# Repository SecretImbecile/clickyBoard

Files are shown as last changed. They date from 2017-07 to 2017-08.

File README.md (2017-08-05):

# clickyBoard
A Raspberry Pi add-on board that adds a simple switch and LED circuit for GPIO programming, using mechanical keyboard switches

Read the [documentation file](Documentation/clickyBoard.pdf).

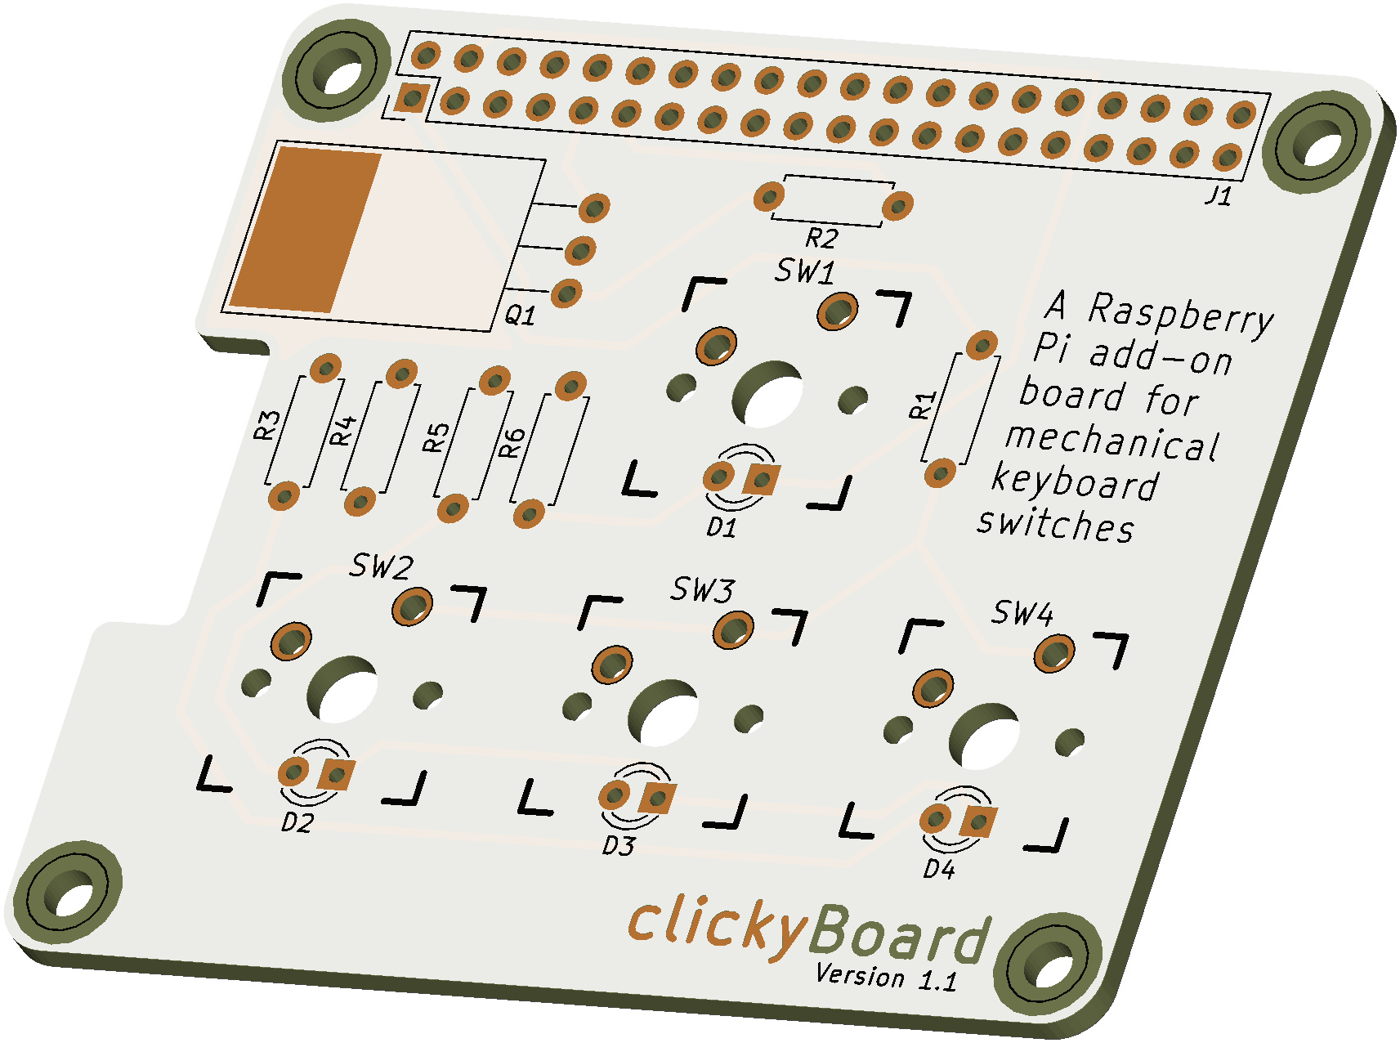
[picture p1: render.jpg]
clickyBoard PCB render


## Keyboard.pretty

Kicad files uses [Keyboard.pretty](https://github.com/stormbard/Keyboard.pretty), the KiCad Module Repository for keyboard PCB creation.

## FAQ

### What does clickyBoard add to my Pi?

clickyBoard adds a simple circuit to your Raspberry Pi for GPIO programming, featuring four input switches, as well as LED backlighting which can be controlled with a single output.

The board uses Cherry MX compatible switches, which are popular keyboard switches, that are widely and cheaply available along with compatible keycaps.

### Has the design been tested?

clickyBoard version 1.0 was manufactured and tested, and the discovered errors were rectified in board version 1.1. This latest version has not been manufactured as of yet, so please perform your own checks before sending the design off to be manufactured.

### Is this a HAT?

Not quite. The Raspberry Pi HAT [specification](https://github.com/raspberrypi/hats) requires a HAT to have an ID EEPROM. To keep this add-on board simple to assemble, this has been ommited. The clickyboard does adhere to the HAT mechanical specifications.

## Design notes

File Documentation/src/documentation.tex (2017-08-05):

\documentclass[10pt, a4paper, onesided]{article}

\usepackage{dingbat}
\usepackage{graphicx}
\usepackage{enumitem}
\renewcommand{\familydefault}{\sfdefault}
\usepackage[colorlinks=false]{hyperref}

\usepackage{listings}
\lstset{basicstyle=\small\ttfamily,breaklines=true}

\setlength{\parskip}{6pt}
\setlength{\parindent}{0pt}

%opening
\title{\textbf{clickyBoard} Documentation}
\author{}
\date{}

\begin{document}
\maketitle
\vspace{-60pt}

\begin{center}
	\textit{For board version 1.1}
\end{center}
\vspace{-12pt}
Download this document at \href{https://github.com/SecretImbecile/clickyBoard}{github.com/SecretImbecile/clickyBoard}
\tableofcontents

\section{The clickyBoard}

	The \textit{clickyBoard} is an add-on board for the Raspberry Pi computer (model B+ or later), which adds a simple switch and LED circuit for use in GPIO programming.
	
	The clickyBoard has been designed to use Cherry MX series switches or compatible switches from other manufacturers, designed for use in keyboards that are widely available and cheaply purchased.
	
	The board, through the Raspberry PI GPIO, provides four push-buttons inputs, as well as a single output through which you can control the four backlight LEDs under each key.
	
	In addition to technical documentation, this document also includes a parts list and assembly guide, for users wishing to assemble their own clickyBoard from scratch, or kit form.

\newpage
\section{Parts Required}

	The following components are required to fully populate a clickyBoard:
	
	\begin{itemize}[noitemsep]
		\item two $1 k\Omega$ resistors
		\item four T1 (3mm) LEDs
		\item four resistors, of a value determined in \autoref{LEDresistors}
		\item one TO-220 package logic level power MOSFET
		\item four Cherry MX compatible switches
		\item a female 40-pin connector for the Raspberry Pi GPIO header\footnote{a $2\times20$ header with $2.54 mm$ ($0.1"$) pitch}
	\end{itemize}
	
	\subsection{Mechanical Keyboard Switches}
	
	The clickyBoard has mounting holes for MX series or compatible switches. These are switches designed for use in premium computer keyboards, which are widely available, along with compatible keycaps.
	
	\begin{figure}[h]
		\centering
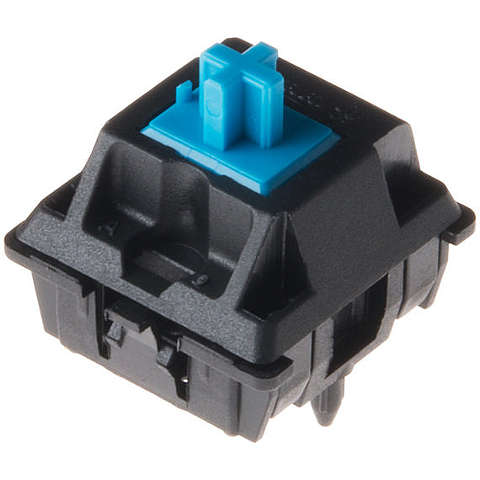
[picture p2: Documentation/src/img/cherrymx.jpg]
		
		\caption{A Cherry MX Blue switch}
		\label{fig:cherrymx}
	\end{figure}
	
	If you require quick delivery, the german manufactured \textbf{Cherry MX} series of switches are more readily available from several on-line retailers. In the United Kingdom, one possibility would be a computer hardware retailer like \href{http://www.kustompcs.co.uk/acatalog/Keys_and_Accessories.html}{kustompcs.co.uk}. In the US and internationally, \href{http://www.wasdkeyboards.com/index.php/products/keyboard-parts.html}{wasdkeyboards.com} specialises in mechanical keyboard parts. Cherry switches are likely to cost around \pounds1 per switch.
	
	If you're willing to wait for shipping from China, there are several manufacturers that make compatible switches, notably \textbf{Gateron} and \textit{Kailh} switches. Gateron switches can be purchased on eBay for as little as 10 for \pounds1.
	
	There are several types of MX switch available, denoted by the colour of their centre plunger, as shown in \autoref*{fig:cherrymx}. We recommend \textbf{blue} coloured switches, for full authentic clickiness, but others are available.
	
	If possible, opt for `\textbf{PCB mount}' switches (sometimes referred to as `5-pin'), as these have additional plastic pegs which will ensure the switches are correctly oriented. Using `plate mount' switches will usually result in slightly misaligned switches.
	
	\begin{center}
	\begin{tabular}{c|c|c|c}
		Switch Colour & Click & Tactile Bump & Heavy Spring \\ 
		\hline 
		Blue & \checkmark & \checkmark & \\ 
		Green & \checkmark & \checkmark & \checkmark \\ 
		Brown &  & \checkmark & \\ 
		Clear &  & \checkmark & \checkmark \\ 
		Red &  &  & \\ 
		Black &  &  & \checkmark \\ 
	\end{tabular}
	\end{center}

	\subsection{LED and Resistor Choice}
	\label{LEDresistors}

	To fit within the housing of an MX compatible switch, a 3mm (T1) LED must be chosen.
	
	To provide sufficient current, the LEDs on the clickyBoard are powered through the Raspberry Pi's 5 volt supply, rather than the current-limited 3V3 GPIO pins, and are instead controlled using a power MOSFET and a single GPIO output.
	
	Each LED has a resistor in series. The required resistance for the circuit can be calculated using this variant of the standard resistance formula, where $V_s$ is the supply voltage, and $V_f$ is the forward voltage of the chosen LED.
	
	\begin{displaymath}
		R = \frac{V_s - V_f}{I}
	\end{displaymath}
	
	For the red $2 V$ $20 mA$ LEDs used in the schematic, the resistance for the LED resistors was calculated as follows.
	
	\begin{displaymath}
		R = \frac{5 V - 2 V}{20 \times 10^{-3} A} = 150 \Omega
	\end{displaymath}

\newpage
\section{Assembly Guide}

	\subsection*{Soldering Basics}
		This guide will assume that the reader is familiar with basic soldering techniques. The components on the clickyBoard are all through-hole components, so it may be a suitable board for a novice solderer. Be aware that the 40-pin GPIO header can be tricky, especially with an old soldering iron, or thick gauge solder wire.
		
		With that said, here are some resources for learning to solder. Video tutorials are well suited for soldering, as you'll need to be able to identify a good solder joint from a bad one.
		\begin{itemize}[nolistsep]
			\item \textit{Soldering basics and choosing a cheap soldering iron} (00:00--12:00), bigclivedotcom --- \url{https://www.youtube.com/watch?v=aIab66EgfHM}
			\item \textit{EEVblog \#183 - Soldering Tutorial Part 2}, EEVblog --- \url{https://www.youtube.com/watch?v=fYz5nIHH0iY}
		\end{itemize}
	
	\subsection*{Resistors}
	
		For convenience, we always solder components from lowest height to highest, to maintain a steady PCB on which to work. Begin by soldering the two $1 k\Omega$ resistors in slots \texttt{r1} and \texttt{r2}.
		
		Next, solder the resistors for the LEDs that you chose in \autoref{LEDresistors} into the sockets \texttt{r3}--\texttt{r6}.
	
	\subsection*{MOSFET}
	
		Bend the legs of your TO-220 package MOSFET to a 90 degree angle and place it in the socket so that the large metal tab is flush with the PCB. You can optionally solder the tab to the large pad on the board, then solder the three main pins into their holes.
		
		If you are \textbf{not} using a MOSFET to control the LEDs, you should jumper the two topmost pins, either by bridging the holes with solder, or with a piece of wire.
	
	\subsection*{Switches \& LEDs}
	
		\subsubsection*{Switch assembly}
	
			In MX style switches, the 3mm LED sits in a slot at the bottom of the switch, and the leads are fed through holes in the switch housing. It is recommended to place the LED in the switch, then inserting that complete assembly into the board to solder.
			
			Ensure that the polarity of the LED is correct, and the switch is sitting flush with the board with the plastic peg(s) in their respective holes, then solder the connections of both the switch and LED.
	
	\subsection*{40-pin GPIO header}
	
		To complete the \textit{clickyBoard}, solder the 40-pin female header to the board, with the female socket on the reverse side of the board.
		
		If you choose not to solder all of the pins, the following pins are required (GPIO board pinout numbering): 
		\texttt{1 4 9 11 12 13 15 16}, omitting \texttt{11} if a MOSFET was not used.

\newpage
\section{Example Code}

The clickyBoard provides the following GPIO devices (all pins are GPIO board numbers):

\begin{itemize}[nosep]
	\item LED brightness control through pin \textbf{11}
	\item switch inputs through pins \textbf{12}, \textbf{13}, \textbf{15}, and \textbf{16}
\end{itemize}

The switch inputs require the internal GPIO pull-down resistors in the Raspberry Pi to be enabled. enable them by setting up the pins with the \texttt{pull\_up\_down} parameter set to \texttt{GPIO.PUD\_DOWN}.

The following example Python program will demonstrate the functionality of the clickyBoard. (note that \texttt{GPIO.cleanup()} is not run following this program)

\begin{lstlisting}[language=Python,title=clickyboardtest.py,numbers=left]
import RPi.GPIO as GPIO
import time

# Setup Pins
GPIO.setmode(GPIO.BOARD)

GPIO.setup(11, GPIO.OUT)
GPIO.setup(12, GPIO.IN, pull_up_down=GPIO.PUD_DOWN)
GPIO.setup(13, GPIO.IN, pull_up_down=GPIO.PUD_DOWN)
GPIO.setup(15, GPIO.IN, pull_up_down=GPIO.PUD_DOWN)
GPIO.setup(16, GPIO.IN, pull_up_down=GPIO.PUD_DOWN)

# Setup Backlight
pwm = GPIO.PWM(11, 60)
pwm.start(100)

while True:
	#Create a count of the buttons being pressed
	buttons_pressed = 0
	
	if GPIO.input(12) == GPIO.HIGH:
		buttons_pressed += 1
	if GPIO.input(13) == GPIO.HIGH:
		buttons_pressed += 1
	if GPIO.input(15) == GPIO.HIGH:
		buttons_pressed += 1
	if GPIO.input(16) == GPIO.HIGH:
		buttons_pressed += 1
	
	#Reduce PWM brightness based on number of buttons
	pwm.ChangeDutyCycle(100 - (25 * buttons_pressed))
	
	time.sleep(0.1)
	
\end{lstlisting}

\newpage
\section{Technical Documentation}
	\subsection{Schematic design for the clickyBoard}
		\begin{center}
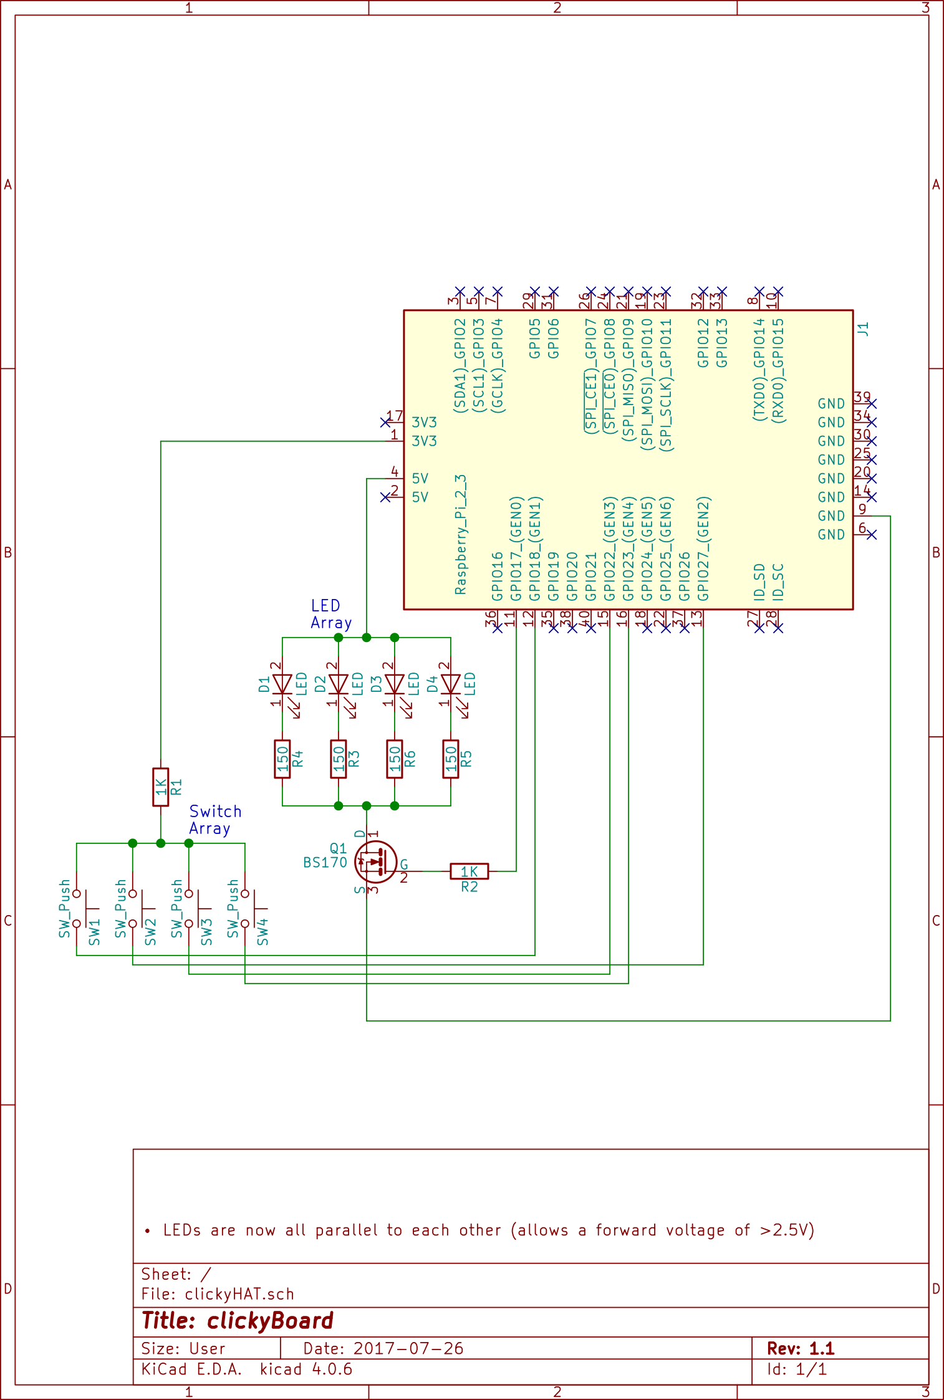
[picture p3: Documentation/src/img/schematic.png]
			
		\end{center}
	
	\newpage
	\subsection{PCB layout for the clickyBoard}
		Gerber outputs (with additional layers) are available on the \href{https://github.com/SecretImbecile/clickyBoard}{GitHub repo}.
		\subsubsection*{Front Copper}
			\begin{center}
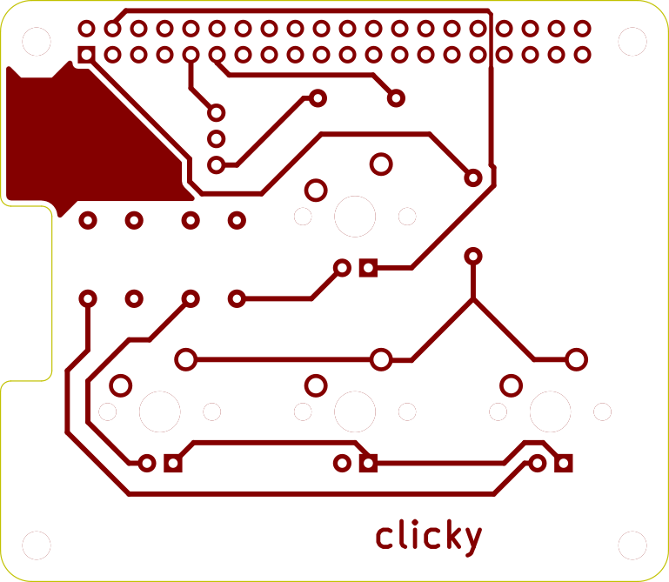
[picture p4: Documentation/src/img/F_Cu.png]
				
			\end{center}
		\subsubsection*{Back Copper}
		\begin{center}
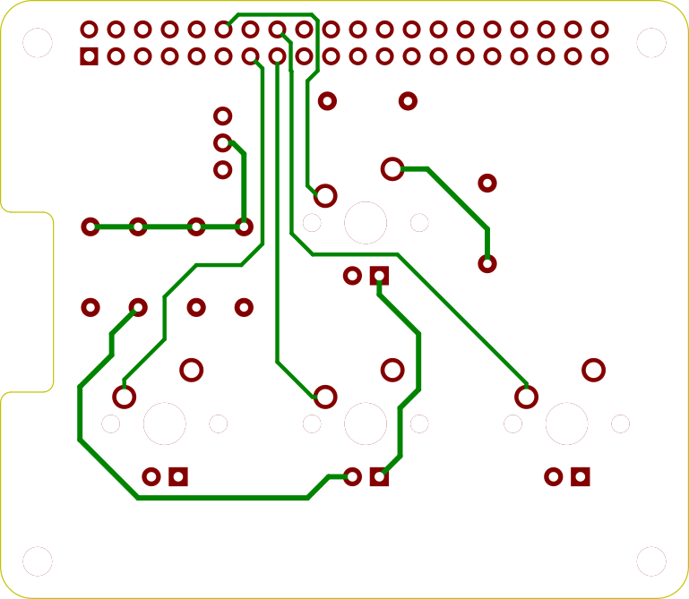
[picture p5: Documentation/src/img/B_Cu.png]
			
		\end{center}
		\subsubsection*{Front Silkscreen}
		\begin{center}
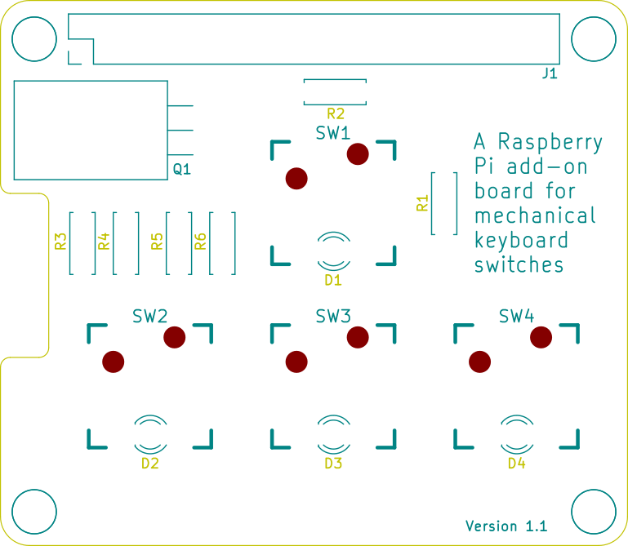
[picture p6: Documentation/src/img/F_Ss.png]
			
		\end{center}
	
	\subsection*{Design rules for PCB}

		The design rules used for this PCB were as follows.
	
		\begin{tabular}{c|c|c|c}
			Clearance & Track Width & Via Size & Silkscreen line thickness \\ 
			\hline 
			$0.2 mm$ & $\ge 0.375 mm$ & n/a & $\ge 0.15 mm$ \\ 
		\end{tabular}

\iffalse
	\subsection{Board errors in version 1.0}
	
		\subsubsection*{MOSFET miswiring}
		\label{MOSFETerror}
		
		Note that the mosfet pads are miswired on version 1.0, and the mosfet should be manually corrected with jumper wires. This has been rectified in version 1.1.
	
		\subsubsection*{LED pad direction}
		\label{LEDerror}
		
		Please note that the solder pads for the LEDs are reversed on board version 1.0. This has been rectified in version 1.1.
		
		By convention, the square solder pad indicates the positive side of a diode. However, because of an update to the \textit{KiCad} software, the pins in the component library were reversed. You should therefore solder the (longer) \textbf{positive} lead of the LEDs into the \textbf{circular} pads. 
		
		\begin{quote}
			\textit{...all diodes in KiCad's standard libraries have seen their pin numbers swapped. This is to be in line with most other software and the IPC standard as well, which states that cathode should be pin 1.}\footnote{\url{https://forum.kicad.info/t/important-announcement-diode-pins-swapped-in-standard-kicad-libraries/820}}
		\end{quote}
	
		\subsubsection*{LED array voltage}
		\label{LEDerror2}
		
		Due to the series arrangement of the LEDs in board version 1.0, blue LEDs would not be useable, this has been rectified in version 1.1.
		
		LEDs were arranged into 2 parallel series as shown in \autoref{fig:documentation}, providing each LED a maximum voltage of 2.5V. Because blue LEDs require a higher forward voltage, most blue and white LEDs will not work on version 1.0 of the clickyBoard, limiting you to red, yellow or green backlighting for most LEDs.
\fi

\newpage
\section{License}

	The complete hardware design for the clickyBoard, including the files made available on the clickyBoard \href{https://github.com/SecretImbecile/clickyBoard}{GitHub repo} and all documentation, are released in accordance with the \href{https://www.oshwa.org/definition/}{Open Source Hardware (OSHW) Definition}, under the \href{https://creativecommons.org/licenses/by-sa/4.0/}{\textbf{Creative Commons Attribution-ShareAlike 4.0 International (CC BY-SA 4.0)}} license.
	
	Every effort has been made to comply with the OSHW statement of principles. If you feel any aspect of the OSHW priciples have been neglected, please raise the issue with the creator (a GitHub issue report would be suitable).
\end{document}

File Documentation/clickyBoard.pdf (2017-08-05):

# clickyBoard Documentation

For board version 1.1
Download this document at github.com/SecretImbecile/clickyBoard

## Contents

1 The clickyBoard | 1
2 Parts Required | 2
3 Assembly Guide | 4
4 Example Code | 6
5 Technical Documentation | 7
6 License | 10

## 1 The clickyBoard

The clickyBoard is an add-on board for the Raspberry Pi computer (model B+ or later), which adds a simple switch and LED circuit for use in GPIO programming.

The clickyBoard has been designed to use Cherry MX series switches or compatible switches from other manufacturers, designed for use in keyboards that are widely available and cheaply purchased.

The board, through the Raspberry PI GPIO, provides four push-buttons inputs, as well as a single output through which you can control the four backlight LEDs under each key.

In addition to technical documentation, this document also includes a parts list and assembly guide, for users wishing to assemble their own clickyBoard from scratch, or kit form.

1

## 2 Parts Required

The following components are required to fully populate a clickyBoard:

- two 1kΩ resistors
- four T1 (3mm) LEDs
- four resistors, of a value determined in subsection 2.2
- one TO-220 package logic level power MOSFET
- four Cherry MX compatible switches
- a female 40-pin connector for the Raspberry Pi GPIO header¹

### 2.1 Mechanical Keyboard Switches

The clickyBoard has mounting holes for MX series or compatible switches. These are switches designed for use in premium computer keyboards, which are widely available, along with compatible keycaps.

Figure 1: A Cherry MX Blue switch

If you require quick delivery, the german manufactured Cherry MX series of switches are more readily available from several on-line retailers. In the United Kingdom, one possibility would be a computer hardware retailer like kustompcs.co.uk. (http://www.kustompcs.co.uk/acatalog/Keys_and_Accessories.html) In the US and internationally, wasdkeyboards.com (http://www.wasdkeyboards.com/index.php/products/keyboard-parts.html) specialises in mechanical keyboard parts. Cherry switches are likely to cost around £1 per switch.

If you’re willing to wait for shipping from China, there are several manufacturers that make compatible switches, notably Gateron and Kailh switches. Gateron switches can be purchased on eBay for as little as 10 for £1.

There are several types of MX switch available, denoted by the colour of their centre plunger, as shown in Figure 1. We recommend blue coloured switches, for full authentic clickiness, but others are available.

If possible, opt for ‘PCB mount’ switches (sometimes referred to as ‘5-pin’), as these have additional plastic pegs which will ensure the switches are correctly oriented. Using ‘plate mount’ switches will usually result in slightly misaligned switches.

1a 2 × 20 header with 2.54mm (0.1”) pitch

2

Switch Colour | Click | Tactile Bump | Heavy Spring
Blue | D | D
Green | D | D | D
Brown | | D
Clear | | D | D
Red
Black | | | D

### 2.2 LED and Resistor Choice

To fit within the housing of an MX compatible switch, a 3mm (T1) LED must be chosen.

To provide sufficient current, the LEDs on the clickyBoard are powered through the Raspberry Pi’s 5 volt supply, rather than the current-limited 3V3 GPIO pins, and are instead controlled using a power MOSFET and a single GPIO output.

Each LED has a resistor in series. The required resistance for the circuit can be calculated using this variant of the standard resistance formula, where Vs is the supply voltage, and Vf is the forward voltage of the chosen LED.

R =

Vs − Vf
I

For the red 2V 20mA LEDs used in the schematic, the resistance for the LED resistors was calculated as follows.

R =

5V − 2V
20 × 10⁻³A

= 150Ω

3

## 3 Assembly Guide

Soldering Basics

This guide will assume that the reader is familiar with basic soldering techniques. The components on the clickyBoard are all through-hole components, so it may be a suitable board for a novice solderer. Be aware that the 40-pin GPIO header can be tricky, especially with an old soldering iron, or thick gauge solder wire.

With that said, here are some resources for learning to solder. Video tutorials are well suited for soldering, as you’ll need to be able to identify a good solder joint from a bad one.

- Soldering basics and choosing a cheap soldering iron (00:00–12:00), bigclive-dotcom — https://www.youtube.com/watch?v=aIab66EgfHM
- EEVblog #183 - Soldering Tutorial Part 2, EEVblog — https://www.youtube.com/watch?v=fYz5nIHH0iY (https://www.youtube.com/watch?v=fYz5nIHH0iY)

Resistors

For convenience, we always solder components from lowest height to highest, to maintain a steady PCB on which to work. Begin by soldering the two 1kΩ resistors in slots r1 and r2.

Next, solder the resistors for the LEDs that you chose in subsection 2.2 into the sockets r3–r6.

MOSFET

Bend the legs of your TO-220 package MOSFET to a 90 degree angle and place it in the socket so that the large metal tab is flush with the PCB. You can optionally solder the tab to the large pad on the board, then solder the three main pins into their holes.

If you are not using a MOSFET to control the LEDs, you should jumper the two topmost pins, either by bridging the holes with solder, or with a piece of wire.

Switches & LEDs

Switch assembly

In MX style switches, the 3mm LED sits in a slot at the bottom of the switch, and the leads are fed through holes in the switch housing. It is recommended to place the LED in the switch, then inserting that complete assembly into the board to solder.

Ensure that the polarity of the LED is correct, and the switch is sitting flush with the board with the plastic peg(s) in their respective holes, then solder the connections of both the switch and LED.

4

40-pin GPIO header

To complete the clickyBoard, solder the 40-pin female header to the board, with the female socket on the reverse side of the board.

If you choose not to solder all of the pins, the following pins are required (GPIO board pinout numbering): 1 4 9 11 12 13 15 16, omitting 11 if a MOSFET was not used.

5

## 4 Example Code

The clickyBoard provides the following GPIO devices (all pins are GPIO board numbers):

- LED brightness control through pin 11
- switch inputs through pins 12, 13, 15, and 16

The switch inputs require the internal GPIO pull-down resistors in the Raspberry Pi to be enabled. enable them by setting up the pins with the pull up down parameter set to GPIO.PUD DOWN.

The following example Python program will demonstrate the functionality of the clickyBoard. (note that GPIO.cleanup() is not run following this program)

clickyboardtest.py

1 | import RPi . GPIO as GPIO
2 | import time
3
4 | # Setup Pins
5 | GPIO . setmode ( GPIO . BOARD )
6
7 | GPIO . setup (11 , GPIO . OUT )
8 | GPIO . setup (12 , GPIO . IN , pull_up_down = GPIO . PUD_DOWN )
9 | GPIO . setup (13 , GPIO . IN , pull_up_down = GPIO . PUD_DOWN )
10 | GPIO . setup (15 , GPIO . IN , pull_up_down = GPIO . PUD_DOWN )
11 | GPIO . setup (16 , GPIO . IN , pull_up_down = GPIO . PUD_DOWN )
12
13 | # Setup Backlight
14 | pwm = GPIO . PWM (11 , 60)
15 | pwm . start (100)
16
17 | while True :
18 | # Create a count of the buttons being pressed
19 | buttons_pressed = 0
20
21 | if GPIO . input (12) == GPIO . HIGH :
22 | buttons_pressed += 1
23 | if GPIO . input (13) == GPIO . HIGH :
24 | buttons_pressed += 1
25 | if GPIO . input (15) == GPIO . HIGH :
26 | buttons_pressed += 1
27 | if GPIO . input (16) == GPIO . HIGH :
28 | buttons_pressed += 1
29
30 | # Reduce PWM brightness based on number of buttons
31 | pwm . ChangeDutyCycle (100 - (25 * buttons_pressed ) )
32
33 | time . sleep (0.1)

6

## 5 Technical Documentation

### 5.1 Schematic design for the clickyBoard

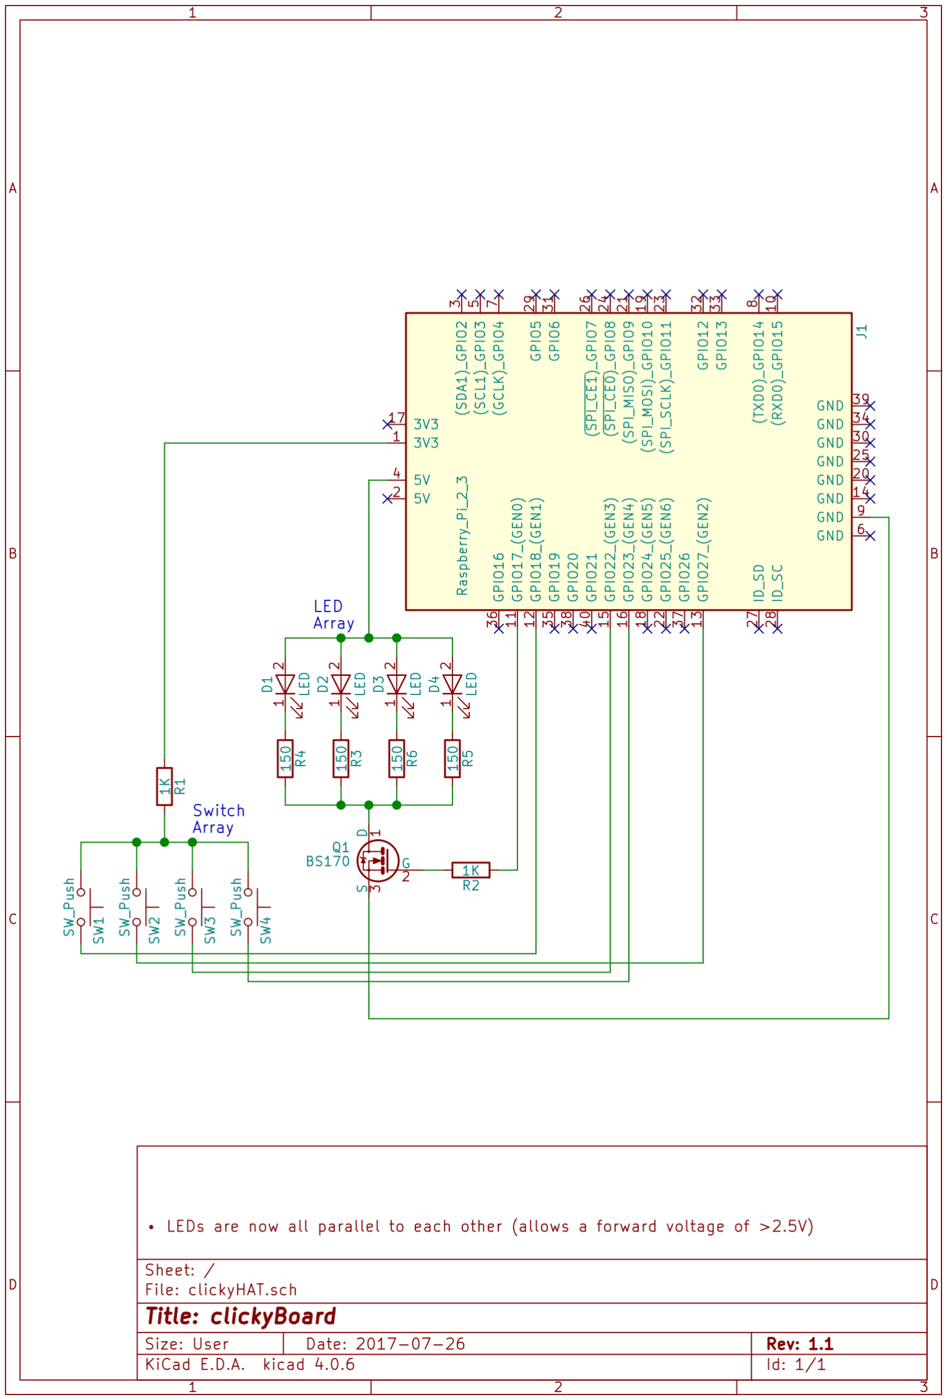
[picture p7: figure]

7

### 5.2 PCB layout for the clickyBoard

Gerber outputs (with additional layers) are available on the GitHub repo. (https://github.com/SecretImbecile/clickyBoard)

Front Copper

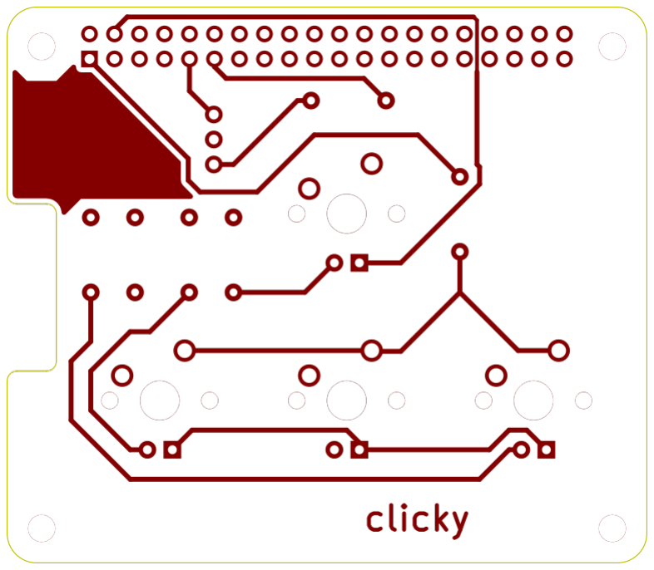
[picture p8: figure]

Back Copper

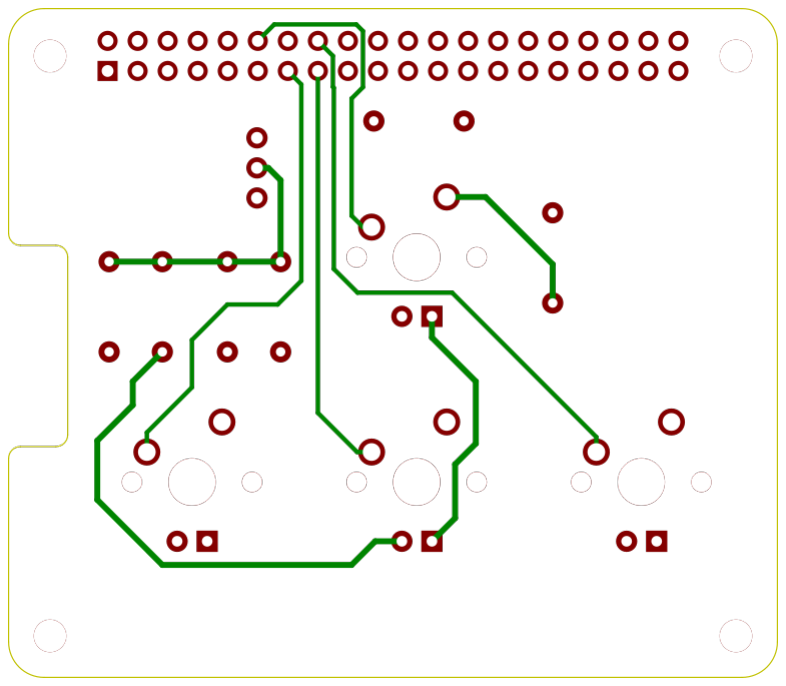
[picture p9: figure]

8

Front Silkscreen

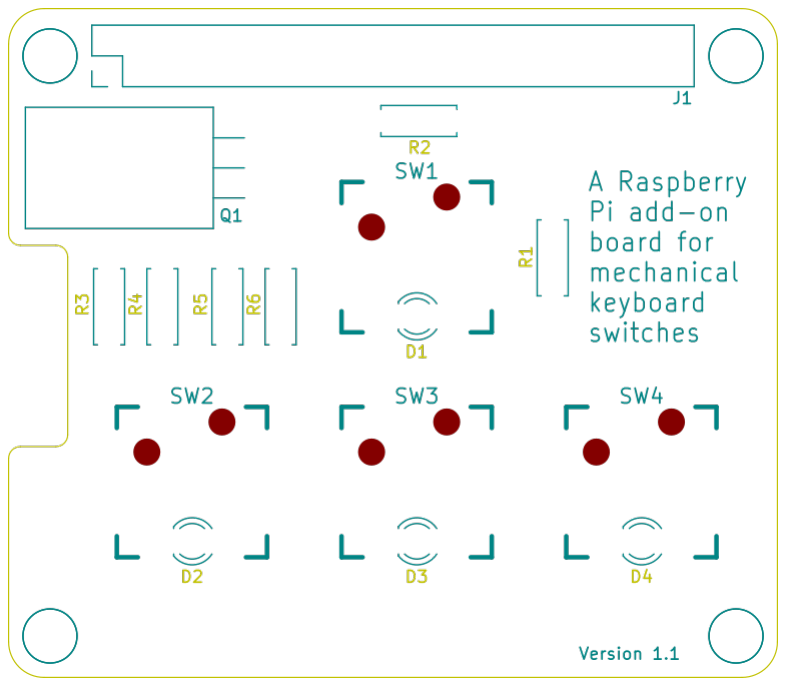
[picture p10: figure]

Design rules for PCB

The design rules used for this PCB were as follows.

Clearance | Track Width | Via Size | Silkscreen line thickness
0.2mm | ≥ 0.375mm | n/a | ≥ 0.15mm

9

## 6 License

The complete hardware design for the clickyBoard, including the files made available on the clickyBoard GitHub repo (https://github.com/SecretImbecile/clickyBoard) and all documentation, are released in accordance with the Open Source Hardware (OSHW) Definition, (https://www.oshwa.org/definition/) under the Creative Commons Attribution-ShareAlike 4.0 International (CC BY-SA 4.0) (https://creativecommons.org/licenses/by-sa/4.0/) license.

Every effort has been made to comply with the OSHW statement of principles. If you feel any aspect of the OSHW priciples have been neglected, please raise the issue with the creator (a GitHub issue report would be suitable).

10

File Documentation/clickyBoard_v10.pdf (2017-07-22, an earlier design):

# Documentation for the clickyBoard

Download this document at github.com/SecretImbecile/clickyBoard

## Contents

1 The clickyBoard | 1
2 Parts Required | 2
3 Assembly Guide | 4
4 Example Code | 6
5 Technical Documentation | 7
6 License | 9

## 1 The clickyBoard

The clickyBoard is an add-on board for the Raspberry Pi computer (model B+ or later), which adds a simple switch and LED circuit for use in GPIO programming.

The clickyBoard has been designed to use Cherry MX series switches or compatible switches from other manufacturers, designed for use in keyboards that are widely available and cheaply purchased.

The board, through the Raspberry PI GPIO, provides four push-buttons inputs, as well as a single output through which you can control the four backlight LEDs under each key.

In addition to technical documentation, this document also includes a parts list and assembly guide, for users wishing to assemble their own clickyBoard from scratch, or kit form.

1

## 2 Parts Required

The following components are required to fully populate a clickyBoard:

- two 1kΩ resistors
- four T1 (3mm) LEDs
- two/four resistors, of a value determined in subsection 2.2
- one TO-220 package logic level power MOSFET
- four Cherry MX compatible switches
- a female 40-pin connector for the Raspberry Pi GPIO header¹

### 2.1 Mechanical Keyboard Switches

The clickyBoard has mounting holes for MX series or compatible switches. These are switches designed for use in premium computer keyboards, which are widely available, along with compatible keycaps.

Figure 1: A Cherry MX Blue switch

If you require quick delivery, the german manufactured Cherry MX series of switches are more readily available from several on-line retailers. In the United Kingdom, one possibility would be a computer hardware retailer like kustompcs.co.uk. (http://www.kustompcs.co.uk/acatalog/Keys_and_Accessories.html) In the US and internationally, wasdkeyboards.com (http://www.wasdkeyboards.com/index.php/products/keyboard-parts.html) specialises in mechanical keyboard parts. Cherry switches are likely to cost around £1 per switch.

If you’re willing to wait for shipping from China, there are several manufacturers that make compatible switches, notably Gateron and Kailh switches. Gateron switches can be purchased on eBay for as little as 10 for £1.

There are several types of MX switch available, denoted by the colour of their centre plunger, as shown in Figure 1. We recommend blue coloured switches, for full authentic clickiness, but others are available. If possible, opt for ‘PCB mount’ switches (sometimes referred to as ‘5-pin’), as these have additional plastic pegs which will somewhat improve stability on the PCB.

1a 2 × 20 header with 2.54mm (0.1”) pitch

2

Switch Colour | Click | Tactile Bump | Heavy Spring
Blue | D | D
Green | D | D | D
Brown | | D
Clear | | D | D
Red
Black | | | D

### 2.2 LED and Resistor Choice

To fit within the housing of an MX compatible switch, a 3mm (T1) LED must be chosen.

To provide ample current, the LEDs on the clickyBoard are powered through the Raspberry Pi’s 5 volt supply, with the LEDs arranged in two parallel series, as shown in Figure 2.

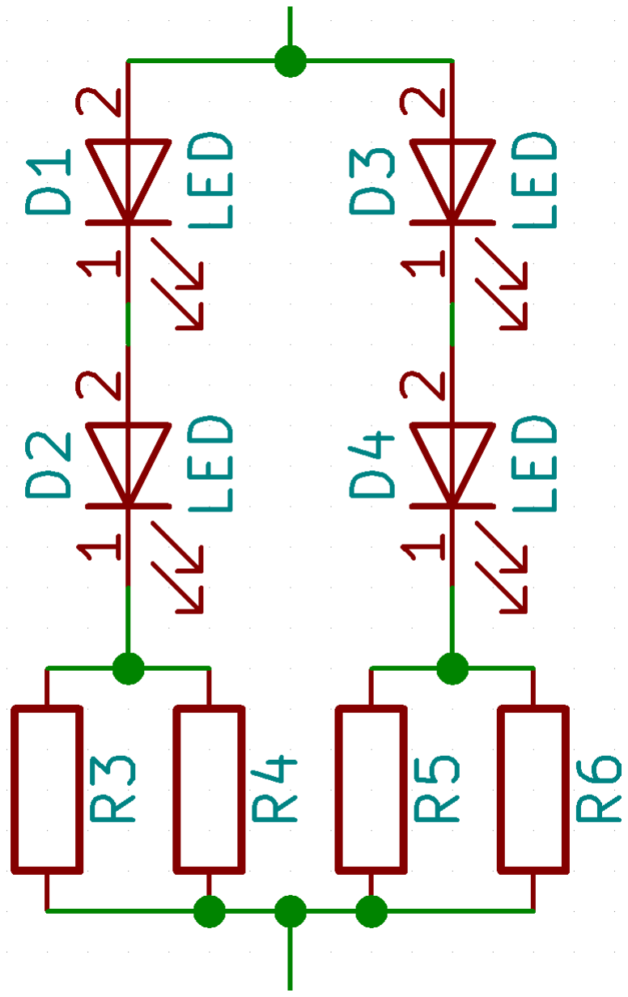
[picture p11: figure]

Figure 2: Wiring schematic for the four resistor sockets

The required resistance for the circuit can be calculated using the standard formula, where Vs is the supply voltage, and Vf is the forward voltage of the chosen LED.

R =

Vs − Vf
I

As each half has two LEDs in series, the forward voltage used is double the value of a single LED. For the 2V 20mA LEDs used in the schematic, the resistance was calculated as follows.

R =

5V − (2 × 2V )
20 × 10⁻³

= 50Ω

The circuit can therefore be completed with two 50Ω resistors. Two additional spaces are provided, so four 100Ω resistors could be used if they are more readily available.

3

## 3 Assembly Guide

Soldering Basics

This guide will assume that the reader is familiar with basic soldering techniques. The components on the clickyBoard are all through-hole components, so it may be a suitable board for a novice solderer. Be aware that the 40-pin GPIO header can be tricky, especially with an old soldering iron, or thick gauge solder wire.

With that said, here are some resources for learning to solder. Video tutorials are well suited for soldering, as you’ll need to be able to identify a good solder joint from a bad one.

- Soldering basics and choosing a cheap soldering iron (00:00–12:00), bigclive-dotcom — https://www.youtube.com/watch?v=aIab66EgfHM
- EEVblog #183 - Soldering Tutorial Part 2, EEVblog — https://www.youtube.com/watch?v=fYz5nIHH0iY (https://www.youtube.com/watch?v=fYz5nIHH0iY)

Resistors

For convenience, we always solder components from lowest height to highest, to maintain a steady PCB on which to work. Begin by soldering the two 1kΩ resistors in slots r1 and r2.

Next, solder the resistors for the LED array that you chose in subsection 2.2 into the sockets r3–r6. If you are using two resistors, ensure the circuit is completed1 in accordance to Figure 2.

MOSFET

Bend the legs of your TO-220 package MOSFET to a 90 degree angle and place it in the socket so that the large metal tab is flush with the PCB, then solder the three pins. You can optionally solder the tab to the plated mounting hole.

If you are not using a MOSFET to control the LEDs, you should jumper the two outermost pins with a piece of insulated wire or an ≈ 0Ω resistor. Ensure that the jumper wire does not short with the centre contact pad.

Switches & LEDs

Erratum: LED pad direction

Please note that the solder pads for the LEDs are reversed. By convention, the square solder pad indicates the positive side of a diode. However, because of an update to the KiCad software, the pins in the component library were reversed. You should therefore solder the (longer) positive lead of the LEDs into the circular pads.

4

...all diodes in KiCad’s standard libraries have seen their pin numbers swapped. This is to be in line with most other software and the IPC standard as well, which states that cathode should be pin 1.²

Switch assembly

In MX style switches, the 3mm LED sits in a slot at the bottom of the switch, and the leads are fed through holes in the switch housing. It is recommended to place the LED in the switch, then inserting that complete assembly into the board to solder.

Ensure that the polarity of the LED is correct, and the switch is sitting flush with the board with the plastic peg(s) in their respective holes, then solder the connections of both the switch and LED.

40-pin GPIO header

To complete the clickyBoard, solder the 40-pin female header to the board, with the female socket on the reverse side of the board.

If you choose not to solder all of the pins, the following pins are required (GPIO board pinout numbering): 1 4 9 11 12 13 15 16, omitting 11 if a MOSFET was not used.

2https://forum.kicad.info/t/important-announcement-diode-pins-swapped-in-standard-kicad-libraries/

820 (https://forum.kicad.info/t/important-announcement-diode-pins-swapped-in-standard-kicad-libraries/820)

5

## 4 Example Code

The clickyBoard provides the following GPIO devices (all pins are GPIO board numbers):

- LED brightness control through pin 11
- switch inputs through pins 12, 13, 15, and 16

The switch inputs require the internal GPIO pull-down resistors in the Raspberry Pi to be enabled. enable them by setting up the pins with the pull up down parameter set to GPIO.PUD DOWN.

The following example Python program will demonstrate the functionality of the clickyBoard. (note that GPIO.cleanup() is not run following this program)

clickyboardtest.py

1 | import RPi . GPIO as GPIO
2 | import time
3
4 | # Setup Pins
5 | GPIO . setmode ( GPIO . BOARD )
6
7 | GPIO . setup (11 , GPIO . OUT )
8 | GPIO . setup (12 , GPIO . IN , pull_up_down = GPIO . PUD_DOWN )
9 | GPIO . setup (13 , GPIO . IN , pull_up_down = GPIO . PUD_DOWN )
10 | GPIO . setup (15 , GPIO . IN , pull_up_down = GPIO . PUD_DOWN )
11 | GPIO . setup (16 , GPIO . IN , pull_up_down = GPIO . PUD_DOWN )
12
13 | # Setup Backlight
14 | pwm = GPIO . PWM (11 , 60)
15 | pwm . start (100)
16
17 | while True :
18 | # Create a count of the buttons being pressed
19 | buttons_pressed = 0
20
21 | if GPIO . input (12) == GPIO . HIGH :
22 | buttons_pressed += 1
23 | if GPIO . input (13) == GPIO . HIGH :
24 | buttons_pressed += 1
25 | if GPIO . input (15) == GPIO . HIGH :
26 | buttons_pressed += 1
27 | if GPIO . input (16) == GPIO . HIGH :
28 | buttons_pressed += 1
29
30 | # Reduce PWM brightness based on number of buttons
31 | pwm . ChangeDutyCycle (100 - (25 * buttons_pressed ) )
32
33 | time . sleep (0.1)

6

## 5 Technical Documentation

### 5.1 Schematic design for the clickyBoard

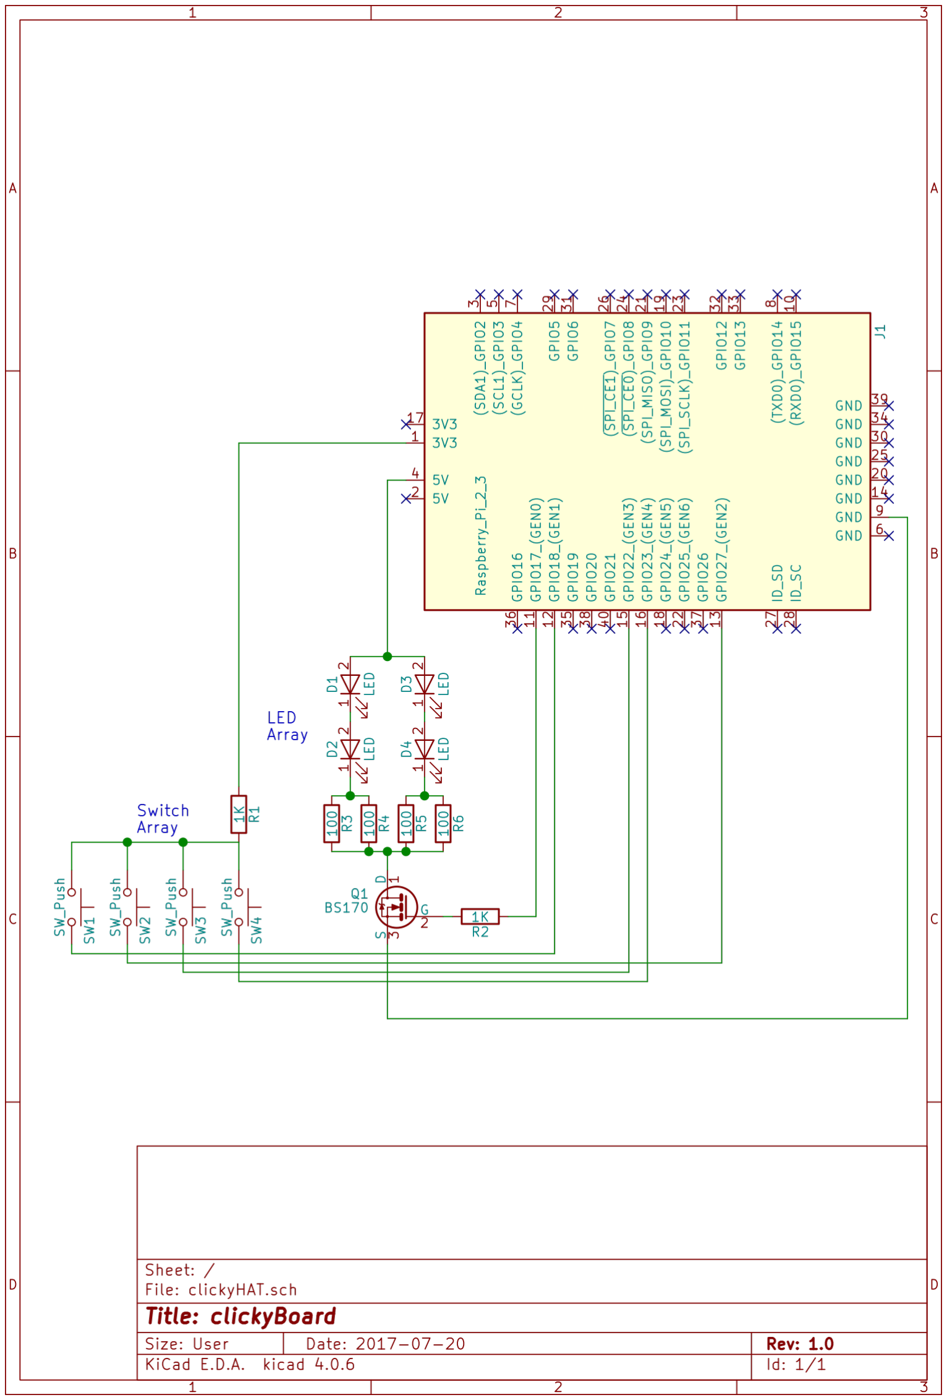
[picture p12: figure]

7

### 5.2 PCB layout for the clickyBoard

Gerber outputs (with additional layers) are available on the github repo. (https://github.com/SecretImbecile/clickyBoard)

Front Copper

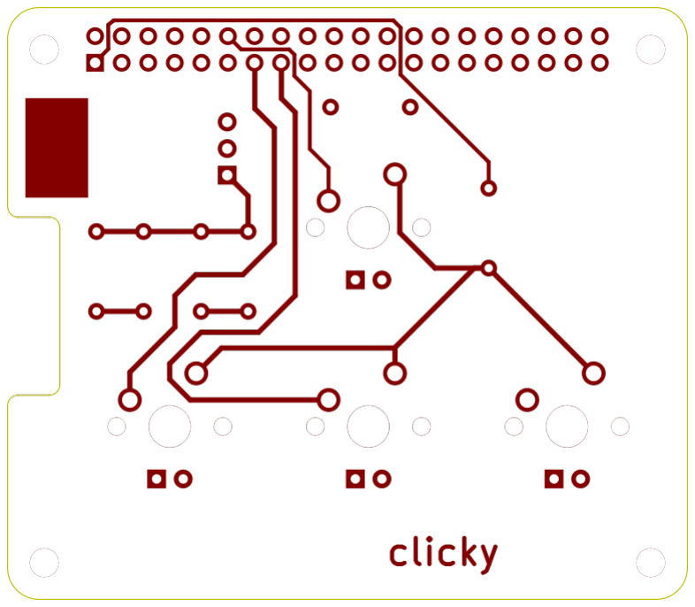
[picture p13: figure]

Back Copper

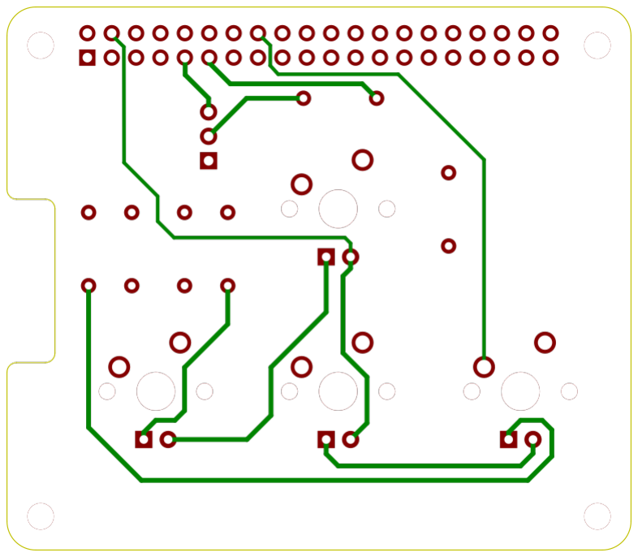
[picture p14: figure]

8

Front Silkscreen

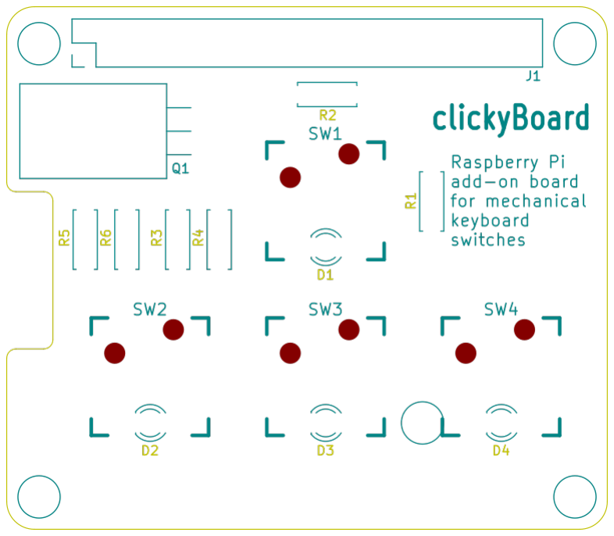
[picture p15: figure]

### 5.3 Design rules for PCB

The design rules used for this PCB were as follows.

Clearance | Track Width | Via Size | Silkscreen line thickness
0.2mm | ≥ 0.375mm | n/a | ≥ 0.15mm

## 6 License

The complete hardware design for the clickyBoard, including the files made available on the clickyBoard Github repo (https://github.com/SecretImbecile/clickyBoard) and all documentation, are released in accordance with the Open Source Hardware (OSHW) Definition, (https://www.oshwa.org/definition/) under the Creative Commons Attribution-ShareAlike 4.0 International (CC BY-SA 4.0) (https://creativecommons.org/licenses/by-sa/4.0/) license.

Every effort has been made to comply with the OSHW statement of principles. If you feel any aspect of the OSHW priciples have been neglected, please raise the issue with the creator (a github issue report would be suitable).

9

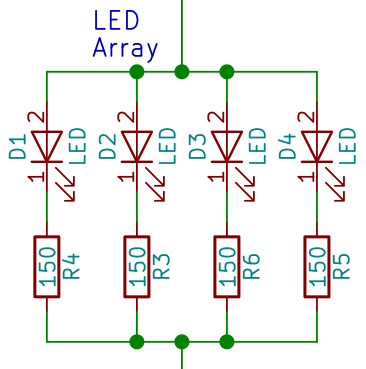
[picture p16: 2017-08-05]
Documentation/src/img/resistor.png

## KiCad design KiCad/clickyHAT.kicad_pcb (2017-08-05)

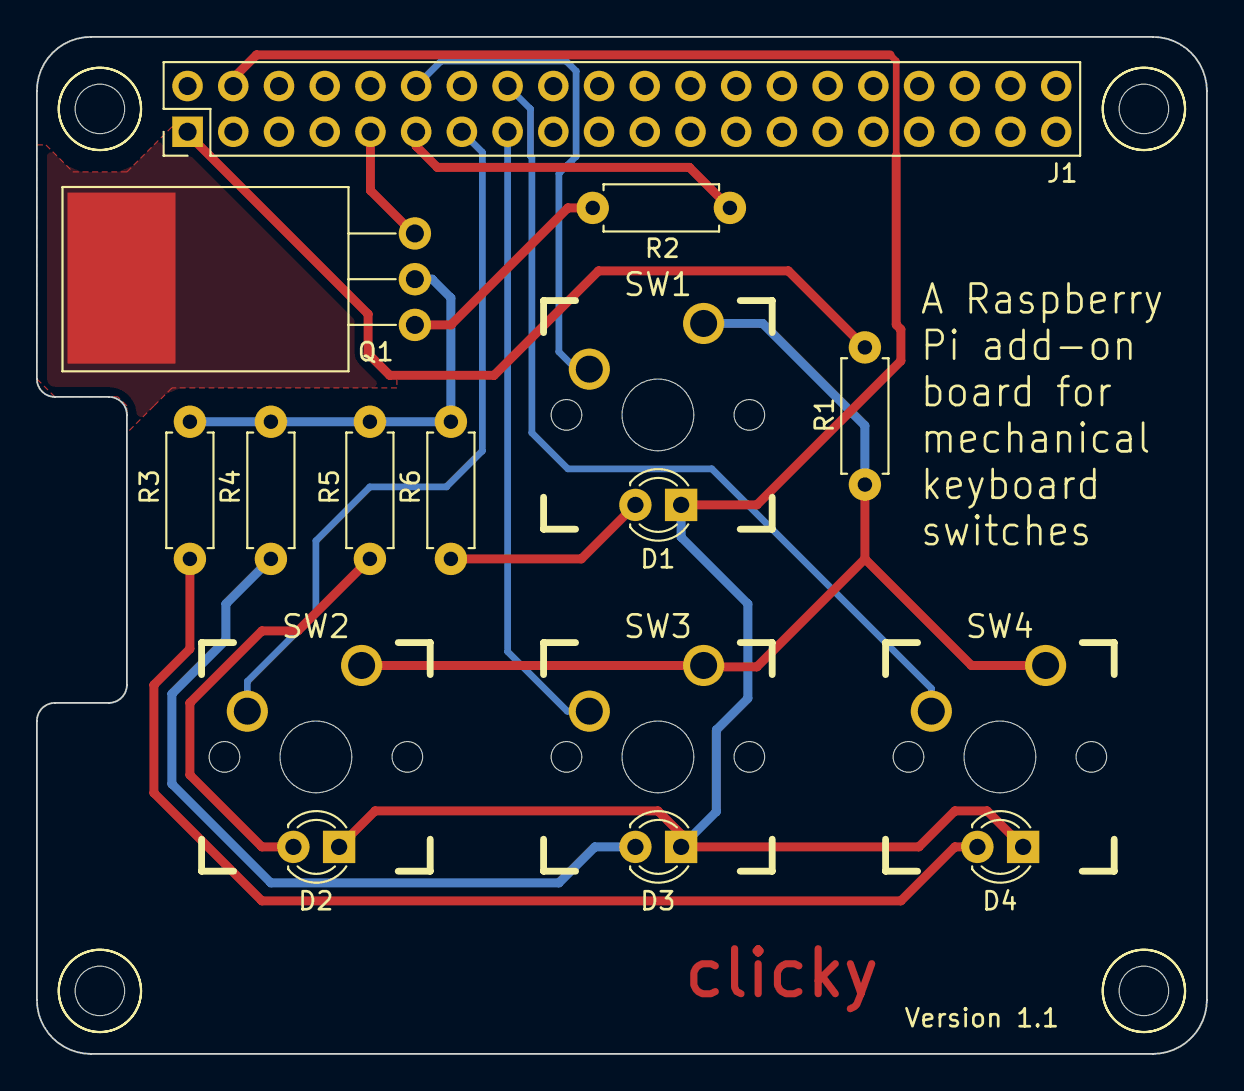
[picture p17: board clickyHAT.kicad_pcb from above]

Board: 2 copper layers, 65.0 x 56.5 mm, 24 parts (0 on the bottom side), 15 nets.

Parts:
D1, D2, D3, D4: LED; LED_D3.0mm
J1: Raspberry_Pi_2_3; Pin_Header_Straight_2x20_Pitch2.54mm
MNT1, MNT2, MNT3, MNT4: 1pin
MNTB1, MNTB2, MNTB3, MNTB4: 1pin
Q1: BS170; TO-220_Horizontal
R1, R2: 1K; R_Axial_DIN0207_L6.3mm_D2.5mm_P7.62mm_Horizontal
R3, R4, R5, R6: 150; R_Axial_DIN0207_L6.3mm_D2.5mm_P7.62mm_Horizontal
SW1, SW2, SW3, SW4: SW_Push; CHERRY_PCB_100H

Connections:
unnamed: D1.1, R6.1
unnamed: D1.2, D2.2, D3.2, D4.2, J1.4
unnamed: D2.1, R5.1
unnamed: D3.1, R4.1
unnamed: D4.1, R3.1
unnamed: J1.1, R1.1
unnamed: J1.9, Q1.3
unnamed: J1.11, R2.1
unnamed: J1.12, SW1.2
unnamed: J1.13, SW2.2
unnamed: J1.15, SW3.2
unnamed: J1.16, SW4.2
unnamed: Q1.2, Q1.4, R3.2, R4.2, R5.2, R6.2
unnamed: Q1.1, R2.2
unnamed: R1.2, SW1.1, SW2.1, SW3.1, SW4.1

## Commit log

2017-07-20 removed board logo until license is decided
    [clickyHAT.kicad_pcb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]
2017-07-21 Completed Documentation
    [clickyHAT-B.Cu.gbl, clickyHAT-B.Mask.gbs, clickyHAT-B.SilkS.gbo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]
2017-07-22 Updated board design
    removed copper fill, updated gerbers are included
    [clickyBoard.drl, clickyBoard.gbl, clickyBoard.gbo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]
2017-07-22 updated board text
    [clickyHAT.kicad_pcb]
2017-07-22 added kicad module link to README.md
2017-07-22 Updated PCB layout in documentation
    removed copper fill
2017-07-24 Updated board error information
2017-08-05 Revision 1.1
    [clickyHAT.kicad_pcb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]
2017-08-05 Documentation updated
    [clickyHAT.kicad_pcb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]
